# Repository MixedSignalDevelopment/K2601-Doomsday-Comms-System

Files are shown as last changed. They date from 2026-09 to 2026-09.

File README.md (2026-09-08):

# Doomsday Comms System (D.C.S.) — Customer Files

**SKU:** OS2601 · **Board revision:** rev B · © Mixed Signal Development GmbH

This package contains everything needed to review, fabricate, assemble, and
re-flash the Doomsday Comms System board — a two-unit personal LoRa text
messenger built on an nRF52840 (BLE) + SX1262 (LoRa 868 MHz) with a 128×64 mono
LCD, jog-wheel input, LRA haptics, piezo, and USB-C LiPo charging.

## Contents

| Folder | What's inside |
|---|---|
| [`01_KiCad_Project/`](01_KiCad_Project/) | Editable source design — KiCad 7 schematic + PCB layout |
| [`02_Gerbers/`](02_Gerbers/) | Fabrication data — RS-274X gerbers + Excellon drills (4-layer) |
| [`03_BOM/`](03_BOM/) | Bill of materials (rev B) with MPNs and LCSC part numbers |
| [`04_3D_Model/`](04_3D_Model/) | Full assembly 3D model (STEP) for enclosure/mechanical fit |
| [`05_Firmware/`](05_Firmware/) | Source firmware (PlatformIO) — bring-up tester + messenger apps |

Each folder has its own `README.md` with the specifics.

## Ownership & licensing

- Design © 2026 **Mixed Signal Development GmbH**.
- **Firmware** is released under the **MIT License** — see
  [`05_Firmware/LICENSE`](05_Firmware/LICENSE).

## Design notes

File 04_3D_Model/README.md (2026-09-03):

# 3D Model

Enclosure design for the assembled Doomsday Comms System (D.C.S., SKU OS2601) board,
for mechanical fit, enclosure design, and review.

## File

- `K2601 DCS.step` —  Enclosure, **STEP (AP214)** format.

## Usage

Open in any MCAD tool that reads STEP (Fusion 360, SolidWorks, FreeCAD,
Onshape, Solid Edge, etc.). Use it to check connector and control placement
(USB-C, jog wheel, LCD window, antenna u.FL/SMA) against the enclosure.

> This is the authoritative mechanical reference for the whole board. The
> per-component 3D models referenced inside the KiCad PCB are **not** bundled
> (see [`../01_KiCad_Project/`](../01_KiCad_Project/)); this STEP file is what you
> need for mechanical work.

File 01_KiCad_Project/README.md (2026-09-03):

# KiCad Project — Schematic & PCB

Editable source design for the Doomsday Comms System (D.C.S., SKU OS2601),
board rev B.

## Files

| File / folder | Description |
|---|---|
| `dcs.kicad_pro` | KiCad project file — open this one |
| `dcs.kicad_sch` | Schematic |
| `dcs.kicad_pcb` | PCB layout (4-layer) |
| `fp-lib-table` | Footprint-library table (project-relative, points at `Misc.pretty`) |
| `Misc.pretty/` | Bundled custom footprint library (`GSC1031YB`) |
| `3D/` | Bundled component 3D models referenced by the PCB |

## Requirements

- **KiCad 7.0 or newer** (the project was authored in KiCad 7).

Open `dcs.kicad_pro` in KiCad, then open the schematic and PCB editors from
the project window.

## Self-contained — no external libraries needed

This project has **no dependency on any machine-specific library path**. It opens
complete on a fresh KiCad install:

- **Footprints** are embedded directly in `dcs.kicad_pcb` (every placed footprint
  carries its full pad/graphics definition), so the layout opens, edits, and
  fabricates without any library at all.
- **Symbols** are cached in `dcs.kicad_sch`, so the schematic opens standalone
  too.
- The one **custom footprint library** the design uses (`GSC1031YB`) is bundled
  in `Misc.pretty/`, and `fp-lib-table` references it with the project-relative
  `${KIPRJMOD}/Misc.pretty` — so you can also place that part into new layouts.
- The per-part **3D models** are bundled in `3D/`; the PCB references them with
  the project-relative `${KIPRJMOD}/3D/…`, so the 3D viewer resolves them with no
  setup. (For a single complete model of the assembled board, the STEP in
  [`../04_3D_Model/`](../04_3D_Model/) is also provided.)

All original absolute local paths were removed — nothing points outside this
folder. The `.kicad_prl` (per-user GUI state) and editor history were not
included.

## Key components

nRF52840 module (Ebyte E73-2G4M08S1C) · SX1262 LoRa (Ai-Thinker Ra-01SH) ·
ST7565 128×64 LCD (GMG12864-06D) · DRV2605L LRA haptics · MCP73833 LiPo charger ·
TLV75533 LDO · TM-1011A jog wheel.

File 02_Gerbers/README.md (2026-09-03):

# Gerbers & Drill Files

Fabrication data for the Doomsday Comms System (D.C.S., SKU OS2601), board
rev B. Generated from KiCad 7. Internal CAD name: **Messager**.

## Board stackup — 4 copper layers

| File | Layer |
|---|---|
| `Messager-F_Cu.gbr` | Top copper |
| `Messager-In1_Cu.gbr` | Inner copper 1 |
| `Messager-In2_Cu.gbr` | Inner copper 2 |
| `Messager-B_Cu.gbr` | Bottom copper |
| `Messager-F_Mask.gbr` / `Messager-B_Mask.gbr` | Solder mask (top / bottom) |
| `Messager-F_Paste.gbr` / `Messager-B_Paste.gbr` | Solder paste stencil (top / bottom) |
| `Messager-F_Silkscreen.gbr` / `Messager-B_Silkscreen.gbr` | Silkscreen (top / bottom) |
| `Messager-Edge_Cuts.gbr` | Board outline |
| `Messager-PTH.drl` | Plated through-holes (Excellon) |
| `Messager-NPTH.drl` | Non-plated holes (Excellon) |
| `Messager-job.gbrjob` | Gerber job file (manifest tying the set together) |

## Formats

- Gerbers: **RS-274X**.
- Drills: **Excellon**.

## Fabrication

A ready-to-upload archive is provided:

- **`OS2601_DCS_RevB_Gerbers.zip`** — all 14 fabrication files, flat (no
  subfolders), ready to drop into a fab's upload form.

Upload it to your PCB fabricator (JLCPCB, PCBWay, Aisler, etc.) and specify a
**4-layer** board. Confirm finished thickness, copper weight, and surface finish
with the vendor per your requirements. (The loose files are also left in this
folder if you prefer to inspect or re-zip them.)

> The gerber/drill filenames keep the internal design name `Messager-*` — only
> the KiCad project and firmware were renamed to `dcs`/OS2601. This is the same
> board; the names are irrelevant to fabrication. Keep them as-is —
> `Messager-job.gbrjob` references the other files by name, so renaming
> individual gerbers would break the job manifest.

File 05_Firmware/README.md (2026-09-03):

# Doomsday Comms System — D.C.S. (SKU OS2601) — bring-up firmware

Menu-driven peripheral tester for the rev-A board (nRF52840 + SX1262),
programmed and debugged over **SWD with an ST-Link V2** (no USB). This is
**not** Meshtastic yet — it is the "bare test firmware" used to prove out every
net before Meshtastic is layered on top. The pin map is encoded once, as a
proper Arduino board variant, so the same variant folder drops into a
Meshtastic build later.

Because there is no USB serial, the console runs over **SEGGER RTT** on the SWD
link: the firmware keeps a text ring-buffer in RAM and OpenOCD serves it as a
bidirectional terminal on `localhost:9090`.

```
platformio.ini                board/env definition + libraries + ST-Link/RTT
boards/dcs_nrf52840.json      custom PlatformIO board (Adafruit nRF52 core)
variants/dcs/                 variant.h + variant.cpp = the authoritative pin map
src/bringup/main.cpp          the bring-up tester (on-LCD wheel-driven menu)
lib/rtt/                       Arduino Stream wrapper over the core's SEGGER RTT
softdevice/                    where the s140 SoftDevice hex goes (not shipped, see below)
flash_softdevice.cfg          OpenOCD: mass-erase + flash the SoftDevice
openocd_rtt.cfg               OpenOCD script: attach ST-Link + serve RTT console
.vscode/tasks.json           SoftDevice flash + "RTT server" + "RTT console" tasks
```

## What it does

The whole tester runs **on the LCD**, driven by the thumbwheel — no host needed.
At boot it shows a splash, turns the backlight on, and drops into a scrolling
main menu. RTT (over SWD) just mirrors a boot/event log for debugging.

**Navigation** (only three inputs exist — wheel R, wheel L, wheel PUSH):

| input | action |
|---|---|
| roll R / L | move the selection, or adjust a value |
| PUSH short (<700 ms)| select / activate |
| PUSH long (>700 ms) | back to the main menu |

> **rev-A note:** SW3's footprint was mis-wired; after a hardware bodge the
> switch works but on swapped pins — firmware maps **P0.12 = press,
> P0.07 = roll R, P0.13 = roll L** (`pollInputs()` in `main.cpp`). Rev-B should
> correct the SW3 footprint so no swap is needed. The RTT console keyboard also
> navigates (`w`/`s` = up/down, `Enter`/space = select, `b` = back), and the
> "Input diagnostic" menu item shows the raw switch pins.

**Menu items** (each maps to a step in the hardware bring-up order):

| item | what it tests | step |
|---|---|---|
| Display + contrast | patterns (frame / all-on / checker / stripes); roll adjusts contrast live | 3 |
| Backlight | roll adjusts PWM brightness | 3 |
| Wheel test | live R / L / PUSH counters + state | 4 |
| Haptic (LRA) | roll picks DRV2605 ROM effect 1–123; push plays | 5 |
| Buzzer tone | roll sets 2–5 kHz; push beeps (single-ended) | 5 |
| Buzzer sweep | 3.6→4.4 kHz resonance sweep | 5 |
| Buzzer LOUD | 4 kHz complementary (antiphase) drive, +6 dB | 5 |
| Battery | live VBAT_MON in mV + bar + status | 7 |
| Radio status | SX1262 SPI init (EU868, DIO2 switch, no TCXO); push = 1 TX (needs antenna) | 6 |
| Sleep (System OFF) | deep-sleep, wake on wheel press | — |

The board's safety rules are honoured in code: **TXEN (P0.28) is never
configured or driven**, `DIO2_AS_RF_SWITCH` is enabled, TCXO is disabled, and
sleep drops LRA_EN / backlight / LCD / radio before System OFF.

---

## Wiring the ST-Link V2

Connect the ST-Link V2 to the TC2030 / SWD header:

| ST-Link V2 pin | board |
|---|---|
| SWDIO | SWDIO |
| SWCLK | SWDCLK |
| GND | GND |
| 3.3V | 3V3 (or power the board from the bench PSU / USB-C) |
| RST (optional) | P0.18 RESET|

The bench PSU can stand in for the battery as usual; the ST-Link only needs
SWDIO/SWCLK/GND to program and to carry the RTT console.

---

## Why a one-time SoftDevice flash is needed

This uses the Adafruit nRF52 core, whose only linker script places the app at
**0x26000** for the **s140 SoftDevice** memory layout. The app therefore cannot
boot unless the SoftDevice (with its MBR at 0x0) is present — a raw app-only
flash programs fine and verifies, but the CPU never reaches `setup()`.

We deliberately **skip the Adafruit UF2/DFU bootloader** (it refuses to
chain-load a raw-flashed app and just sits in DFU). Instead we flash
**MBR + SoftDevice only** (`softdevice/s140_6.1.1_mbr.hex`); with no UICR
bootloader pointer set, the MBR boots SoftDevice → app directly. This is a
one-time step (the equivalent of "flash the bootloader once"); the SoftDevice
survives every subsequent app upload.

> **The SoftDevice hex is not included in this repository.** Nordic's s140 is
> proprietary and is not redistributable here, so you must supply
> `softdevice/s140_6.1.1_mbr.hex` yourself before the flash step below — see
> [`softdevice/README.md`](softdevice/README.md) for where to obtain it.

> The chip does **not** need a pyOCD APPROTECT recovery — this board's nRF52840
> was not locked. If you ever hit a genuinely locked part, `python -m pyocd
> erase --mass -t nrf52840` clears it, but you won't normally need it.

---

## Run it from VS Code

### One-time setup
1. Open this `Firmware` folder in VS Code (**File → Open Folder**).
2. When prompted, install the recommended **PlatformIO IDE** extension
   (`platformio.platformio-ide`). It bundles its own toolchain (and OpenOCD) —
   you do **not** need Python or `pio` on your PATH. First launch downloads the
   nRF52 toolchain (a few minutes).
3. Reopen the folder once PlatformIO finishes initialising. A small **PlatformIO
   toolbar** (house / ✓ / → icons) appears in the blue status bar at the bottom.

### Build
- Click the **✓ (Build)** button in the status bar (or `Ctrl+Alt+B`).
- First build pulls U8g2, Adafruit DRV2605 and RadioLib automatically.
- Verified building clean here: RAM ~5%, Flash ~13%.

### Flash the SoftDevice — ONE TIME, before the first upload
- **Terminal → Run Task… → "Flash SoftDevice (one-time, before first upload)"**.
  This mass-erases and writes MBR + s140. Do it once per board (or after any
  mass-erase). Then continue to Upload below.

### Flash the app over SWD (ST-Link)
- Click the **→ (Upload)** button (or `Ctrl+Alt+U`). PlatformIO drives OpenOCD
  with the ST-Link (plain `swd` transport) to program the app at 0x26000. The
  SoftDevice underneath boots it. Re-run this for every code change.

### Open the RTT console (this is your bring-up terminal)
The console is not a COM port — it comes over SWD via RTT, in two steps:

1. **Terminal → Run Task… → "RTT: OpenOCD server (start first)"**
   — attaches the ST-Link and serves the console on `localhost:9090`.
   Leave this running.
2. **Terminal → Run Task… → "RTT console"**
   — opens the interactive terminal (PlatformIO monitor on `socket://localhost:9090`).

Now press `h` for the menu, then the single-letter commands in the table above.
Typing goes to the board; test output comes back. That terminal *is* your
bring-up console.

> One ST-Link can only be owned by one tool at a time. Upload first (releases
> the probe), then start the OpenOCD server task. If a task can't connect,
> make sure no debug session or other OpenOCD is still holding the probe.

### Source-level debugging (breakpoints)
ST-Link + nRF52 debugging is wired up: **Run → Start Debugging (F5)** launches
OpenOCD + GDB and halts at `setup()`. Set breakpoints, inspect variables, step.
Note this F5 session owns the ST-Link, so stop it before using the RTT tasks
(and vice-versa). For day-to-day bring-up the RTT console is the faster loop.

---

## Command-line equivalent (if you prefer)
PlatformIO installs a CLI at `~/.platformio/penv/Scripts/pio.exe`:
```
pio run                 # build
pio run -t upload       # flash over SWD via ST-Link
# then, for the console:
~/.platformio/packages/tool-openocd/bin/openocd -f openocd_rtt.cfg      # server
pio device monitor --port socket://localhost:9090 --echo               # terminal
```

## Troubleshooting

- **Flash "Verified OK" but nothing runs (no RTT, `setup()` never hit)** — the
  SoftDevice isn't present. Run the one-time **Flash SoftDevice** task, then
  Upload the app again. (Symptom when halted: PC sits below 0x26000.)
- **OpenOCD: "Debug adapter doesn't support 'hla_swd' transport"** — the platform
  default; this project already overrides it to plain `swd` in `platformio.ini`
  and the `.cfg` files. If you add your own OpenOCD invocation, use
  `-c "transport select swd"`, not `hla_swd`.
- **pyOCD `STLink error (29): Bad AP`** — pyOCD's AP scan tripping on this
  ST-Link when it probes the (absent) next access port; it does *not* mean the
  chip is locked. We use OpenOCD (not pyOCD) for flashing, which is unaffected.
- **RTT console is blank** — make sure the OpenOCD server task is running and
  the firmware is actually running (an F5 debug session halts at `setup()` — hit
  Continue). The console only prints once code runs.
- **"unknown command: rtt"** in the OpenOCD task — your bundled OpenOCD is old;
  update PlatformIO (`pio upgrade` / update the PlatformIO IDE extension), which
  pulls a newer `tool-openocd`.
- **Display garbled / shifted a few pixels** — GMG12864 panels vary; in
  `src/main.cpp` swap the `U8G2_ST7565_ERC12864_F_4W_SW_SPI` constructor for the
  `..._ALT_...` variant, or an `NHD_C12864` / `LM6059` profile, and re-tune
  `setContrast()`.
- **Probe busy** — only one of {Upload, F5 debug, RTT OpenOCD task} can own the
  ST-Link at a time. Stop the others first.

## Next step after bring-up
Once every net checks out, this `variants/dcs/` folder is copied into a
Meshtastic firmware checkout as a custom board variant, and the UI becomes a
custom Meshtastic module.

## License
Firmware in this repository is released under the **MIT License** (see
[`LICENSE`](LICENSE)) — © 2026 **Mixed Signal Development GmbH**. When the
hardware design files (schematics, PCB) are published, the customary pairing is
a hardware licence such as **CERN-OHL-S**; this repo covers the firmware only.

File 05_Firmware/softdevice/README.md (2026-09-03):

# SoftDevice (not included)

The Nordic **s140 v6.1.1** SoftDevice is proprietary and is **not redistributed**
in this repository (see Nordic's Software Development Kit license). You must
supply it yourself before the one-time flash step.

## What you need

A combined **MBR + s140 6.1.1** Intel-HEX image named:

```
softdevice/s140_6.1.1_mbr.hex
```

`flash_softdevice.cfg` expects exactly this path/name.

## Where to get it

The matching SoftDevice ships with the Adafruit nRF52 Arduino core (the same
core this project builds against). After PlatformIO has fetched the framework,
it is under:

```
~/.platformio/packages/framework-arduinoadafruitnrf52/cores/nRF5/nordic/softdevice/s140_nrf52_6.1.1_API/
```

and the raw hex is distributed with the Nordic **nRF5 SDK** / the S140 6.1.1
release on Nordic Semiconductor's website. Combine the MBR + SoftDevice into a
single hex (or use the pre-combined image from the Adafruit bootloader release
assets) and save it to the path above.

Because it is proprietary, the file is listed in `.gitignore` — keep it out of
any public fork.

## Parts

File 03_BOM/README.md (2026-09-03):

# Bill of Materials

Production BOM for the Doomsday Comms System (D.C.S., SKU OS2601), board rev B.

## File

- `OS2601_DCS_RevB_BOM.xlsx` — 27 line items, 44 components.

## Columns

- **Placed** — a checkbox column for hand-assembly / line tracking.
- **Designators** — reference designators (e.g. `C1–C4`, `U2`).
- **Value** — component value.
- **Package** — footprint / package (0805, 0603, SOT-23, MSOP-10, …).
- **Qty** — quantity per board.
- **MPN** — manufacturer part number.
- **Notes** — includes **LCSC part numbers** (e.g. `C354262`) for direct ordering,
  plus alternates where called out.

The list is grouped for assembly convenience (SMD passives first, then ICs and
transistor, etc.).

## Sourcing note

LCSC part numbers are given for most parts for convenient ordering / JLCPCB
assembly. A few parts (e.g. the 10 µF `CL21B106KOQNNNE`) have no LCSC number and
should be ordered by **MPN**. Always verify availability and package/value before
placing an order.

> This is the **production** BOM. An internal costing BOM exists but is
> intentionally **not** included in this package.

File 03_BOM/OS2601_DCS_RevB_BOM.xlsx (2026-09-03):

OS-K2601 Messager — Bill of Materials
Rev B · nRF52 BLE + LoRa · USB-C LiPo charging · 27 line items · 44 components
Placed | Designators | Value | Package | Qty | MPN | LCSC OC | Notes
1 · SMD passives (0805 / 0603) flattest parts first
☐ | C1–C4 | 4.7µF | 0805 | 4 | CL21A475KAQNNNE | C354262
☐ | C6, C11 | 1µF | 0805 | 2 | CC0805KKX7R7BB105 | C91186
☐ | C9, C10, C13, C14, C16 | 100nF | 0805 | 5 | CC0805KRX7R9BB104 | C396718
☐ | C12, C15 | 10µF | 0805 | 2 | CL21B106KOQNNNE | C95841 | No LCSC # — order by MPN
☐ | R1, R2 | 5.1k | 0805 | 2 | RC0805FR-075K1L | C84375
☐ | R3 | 2k | 0805 | 1 | RC0805JR-072KL | C114748
☐ | R4 | 22R | 0805 | 1 | RC0805FR-0722RL | C107702
☐ | R5 | 100k | 0805 | 1 | RC0805FR-07100KL | C96346
☐ | R6–R8, R11, R12, R15 | 4.7k | 0805 | 6 | RC0805FR-074K7L | C60816
☐ | R9, R10 | 1M | 0805 | 2 | RC0805FR-071ML | C706228
☐ | R13, R14 | 100R | 0805 | 2 | RC0805FR-07100RL | C105577 | Alt LCSC: C2907218
☐ | F1 | 1A fuse | 0603 | 1 | JB06F1001R | C151139 | No LCSC # — order by MPN
☐ | TH1 | 10k NTC | 0603 | 1 | NTCG164BH103HT1 | C415353
2 · SMD ICs & transistor use flux — mind pin 1
☐ | Q1 | 2N7002 | SOT-23 | 1 |  | C916396
☐ | U2 | MCP73833 | MSOP-10 | 1 | MCP73833T-AMI/UN |  | Mind pin 1 · no LCSC #, cheaper on Digikey
☐ | U3 | TLV75533 | SOT-23-5 | 1 | TLV75533PDYDR | C28642215
☐ | U7 | DRV2605L | MSOP-10 | 1 | DRV2605LDGSR | C527464 | Mind pin 1
3 · LED & switches LED is directional
☐ | D1 | Side LED | 4×1.4mm | 1 | XL-4008SURC | C2843771 | Polarity — check cathode mark
☐ | SW1 | Push button | Side SMD | 1 | MPTCLG-Q-T/R | C240296
☐ | SW3 | Slide switch | TM-1011A | 1 | TM-1011A | C318960
4 · Modules & sounder keep antennas clear of solder
☐ | U1 | E73-2G4M08S1C | SMD module | 1 | E73-2G4M08S1C | C356849 | nRF52 BLE
☐ | U8 | Ra-01SH | SMD module | 1 | Ra-01SH | C2764087 | LoRa
☐ | U4 | GSC1031YB-3V4000 | SMD buzzer | 1 | GSC1031YB-3V4000 | C255331
☐ |  | Antenna |  | 1 | ANT-868-CW-HD-SMA | Link (https://www.digikey.ch/en/products/detail/te-connectivity-linx/ANT-868-CW-HD-SMA/5592339)
☐ |  | VG0832012 | LRA | 1 | VG0832012 | Link (https://www.digikey.ch/en/products/detail/vybronics-inc/VG0832012/7364317)
☐ | M1 | 12864 display | Module | 1 | 12864-06D | Link (https://de.aliexpress.com/item/1005010600373201.html)
5 · Connectors & programming last — the tall parts
☐ | J1 | PH2.0 battery | JST SMD | 1 |  | C295747 | Check battery polarity
☐ | J2 | USB-C 16P | USB-C SMD | 1 | TYPE-C 16PIN 2MD(073) | C2765186
☐ | TC1 | TC2030-IDC | Tag-Connect | 1 |  |  | Pads only — no part fitted
☐ → pick ☑ from the dropdown (or tick on paper) as you place each part. Solder top to bottom, flattest first. Mixed Signal Development · mixedsignaldev.com

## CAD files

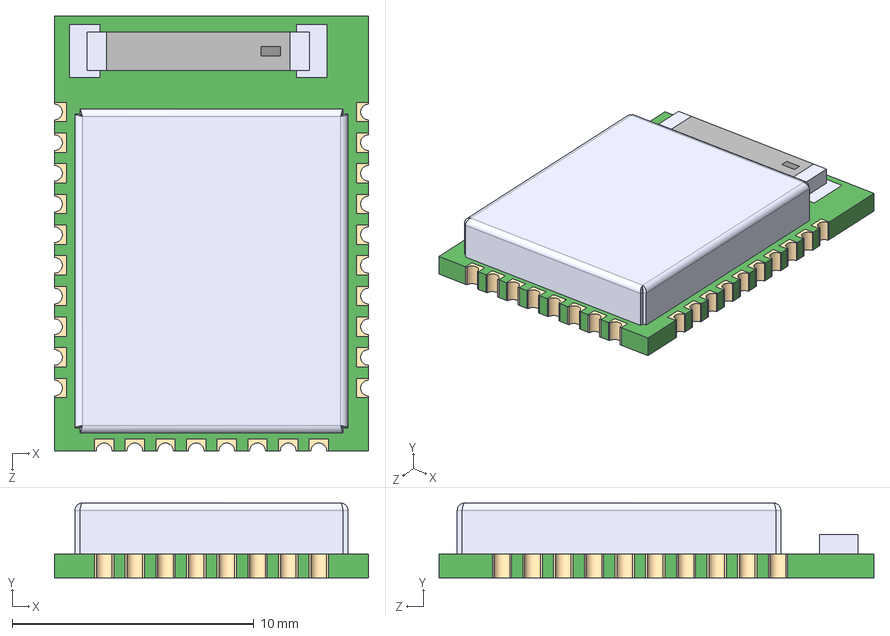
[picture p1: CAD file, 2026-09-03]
01_KiCad_Project/3D/E73-2G4M08S1C.step
13.0 x 3.10 x 18.0 mm

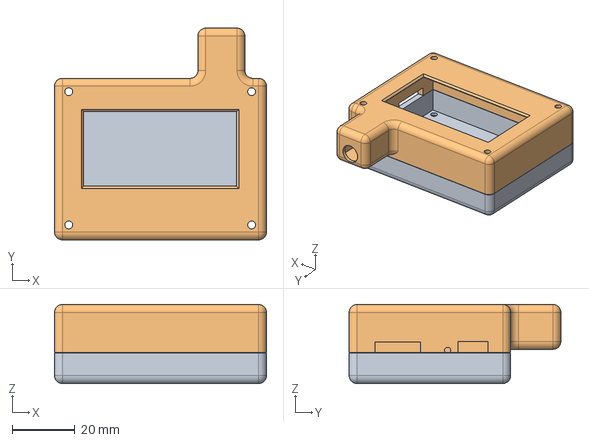
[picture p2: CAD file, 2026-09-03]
04_3D_Model/K2601 DCS.step
67.6 x 67.5 x 25.2 mm

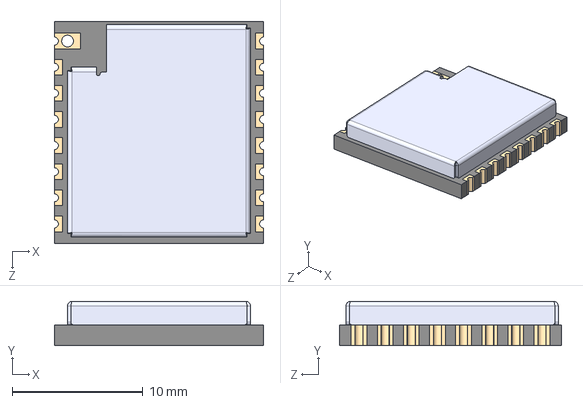
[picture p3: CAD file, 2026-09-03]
01_KiCad_Project/3D/RA-01H.STEP
16.0 x 3.40 x 17.0 mm

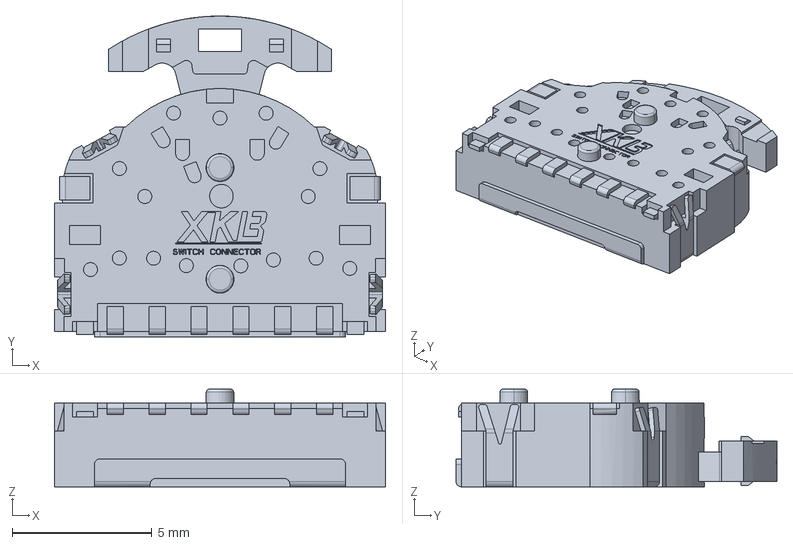
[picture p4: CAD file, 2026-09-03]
01_KiCad_Project/3D/TM-1011A.stp
11.9 x 11.5 x 3.50 mm

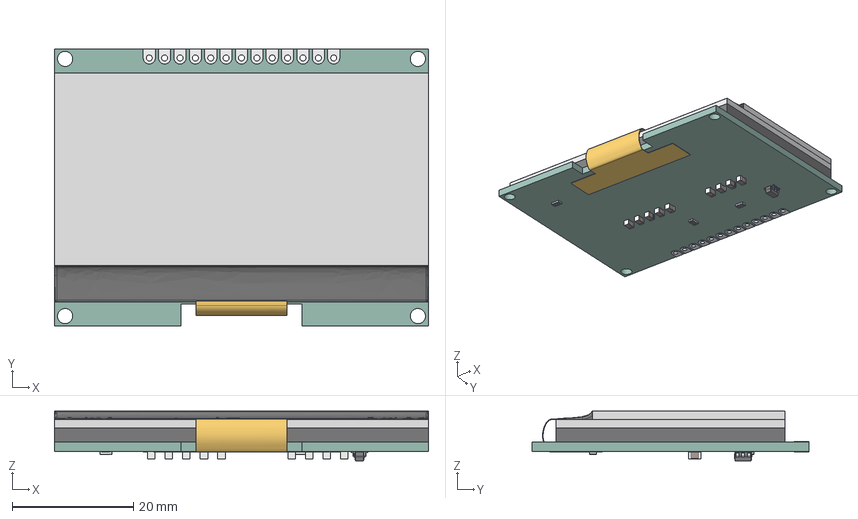
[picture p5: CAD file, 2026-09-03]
01_KiCad_Project/3D/GMG12864-06D.step
61.8 x 45.8 x 8.25 mm
PCB
LED-box
Back glass
Front glass
Ribbon cable
Resin
Hole plates
C_0805_2012Metric x 9
SOT-23-6
R_0805_2012Metric x 3

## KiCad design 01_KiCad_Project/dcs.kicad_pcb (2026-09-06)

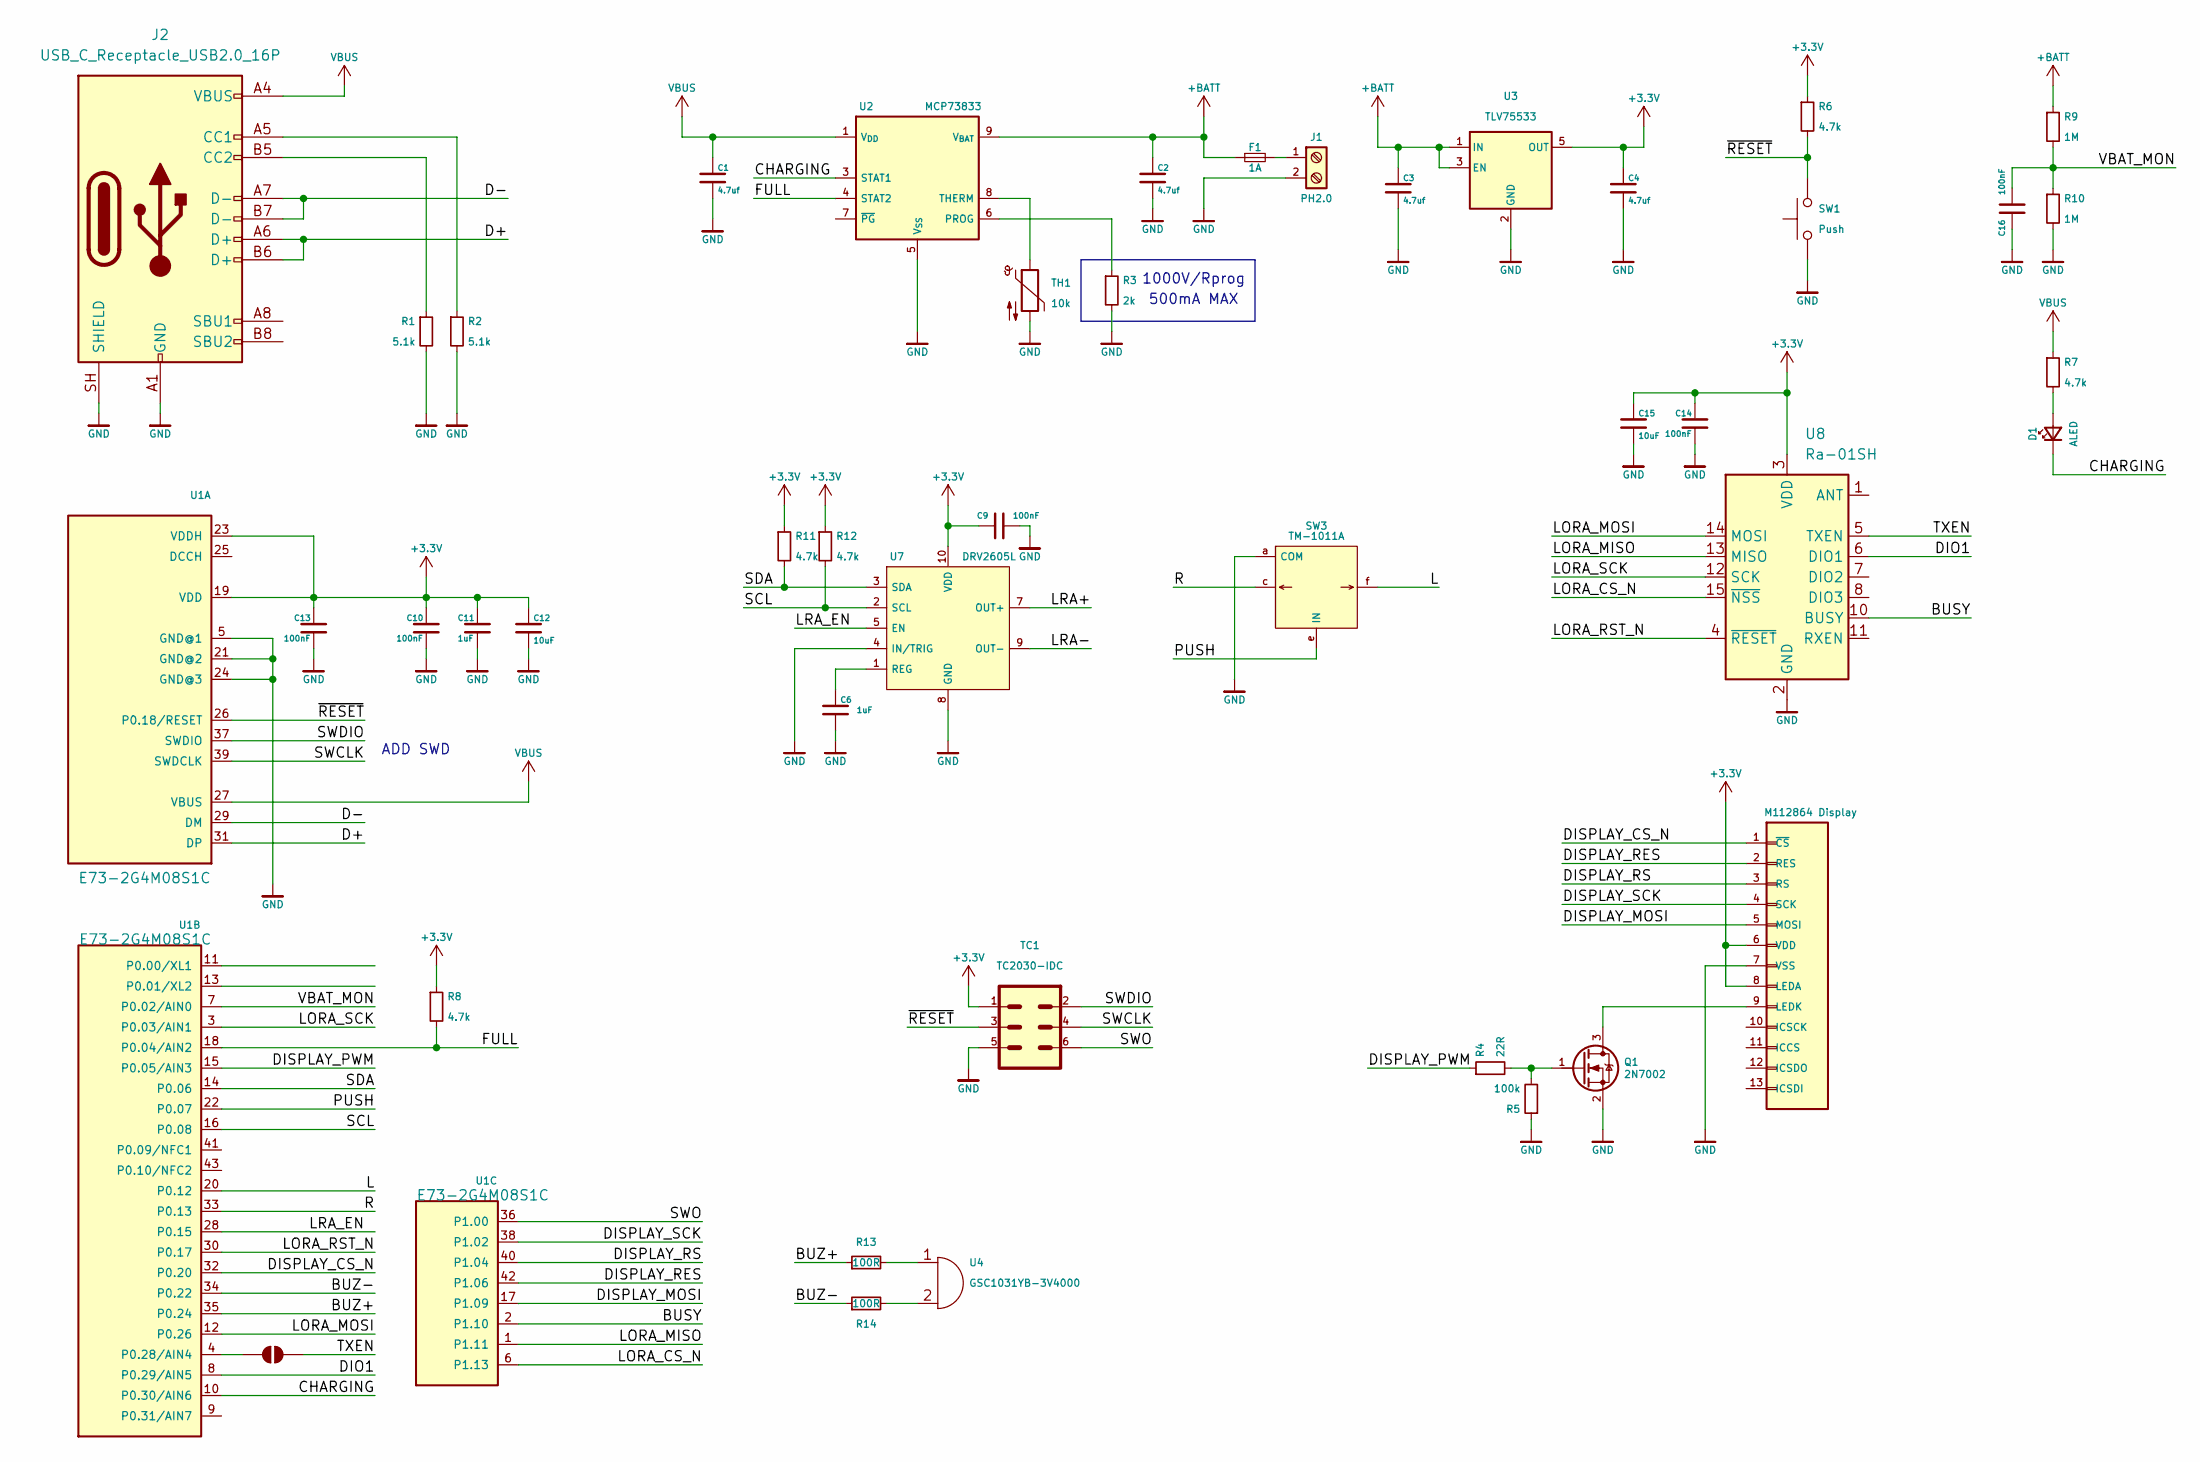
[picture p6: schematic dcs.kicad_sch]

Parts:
C1, C2, C3, C4: 4.7uf; C_0805; MPN CL21A475KAQNNNE; LCSC OC C354262
C6, C11: 1uF; C_0805; MPN CC0805KKX7R7BB105; LCSC OC C91186
C9, C10, C13, C14, C16: 100nF; C_0805; MPN CC0805KRX7R9BB104; LCSC OC C396718
C12, C15: 10uF; C_0805; MPN CL21B106KOQNNNE
D1: ALED; SideLED_4x1.4mm; MPN XL-4008SURC; LCSC OC C2843771
F1: 1A; R_0603; MPN JB06F1001R
J1: PH2.0; JST_PH_S2B-PH-SM4-TB_1x02-1MP_P2.00mm_Horizontal; LCSC OC C295747
J2: USB_C_Receptacle_USB2.0_16P; USB_C_16P_Horizontal; MPN TYPE-C 16PIN 2MD(073); LCSC OC C2765186
JP1: SolderJumper_2; SolderJumper-2_P1.3mm_Open_RoundedPad1.0x1.5mm
M1: 12864 Display; 12864DisplayModule
Q1: 2N7002; SOT-23; LCSC OC C916396
R1, R2: 5.1k; R_0805; MPN RC0805FR-075K1L; LCSC OC C84375
R3: 2k; R_0805; MPN RC0805JR-072KL; LCSC OC C114748
R4: 22R; R_0805; MPN RC0805FR-0722RL; LCSC OC C107702
R5: 100k; R_0805; MPN RC0805FR-07100KL; LCSC OC C96346
R6, R7, R8, R11, R12: 4.7k; R_0805; MPN RC0402FR-074K7L; LCSC OC C60816
R9, R10: 1M; R_0805; MPN RC0805FR-071ML; LCSC OC C706228
R13, R14: 100R; R_0805; MPN RC0805FR-07100RL; LCSC OC C105577
SW1: Push; SideSwitch; MPN MPTCLG-Q-T/R; LCSC OC C240296
SW3: TM-1011A; SlideKnob; MPN TM-1011A; LCSC OC C318960
TC1: TC2030-IDC
TH1: 10k; R_0603; MPN NTCG164BH103HT1; LCSC OC C415353
U1: E73-2G4M08S1C; MPN E73-2G4M08S1C; LCSC OC C356849
U2: MCP73833; MSOP-10_3x3mm_P0.5mm; MPN MCP73833T-AMI/UN
U3: TLV75533; SOT-23-5; MPN TLV75533PDYDR; LCSC OC C28642215
U4: GSC1031YB-3V4000; GSC1031YB; MPN GSC1031YB-3V4000; LCSC OC C255331
U7: DRV2605L; MSOP-10_3x3mm_P0.5mm; MPN DRV2605LDGSR; LCSC OC C527464
U8: Ra-01SH; Ai-Thinker-Ra-01-LoRa; MPN Ra-01SH; LCSC OC C2764087

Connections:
+3.3V: C4.1, C9.1, C10.1, C11.1, C12.1, C13.1, C14.1, C15.1, M1.6 (VDD), M1.8 (LEDA), R6.1, R8.1, R11.1, R12.1, TC1.1, U1.19 (VDD), U1.23 (VDDH), U3.5 (OUT), U7.6 (VDD/NC), U7.10 (VDD), U8.3 (VDD)
+BATT: C2.1, C3.1, F1.1, R9.1, U2.9 (V_{BAT}), U2.10 (V_{BAT}), U3.1 (IN), U3.3 (EN)
/BUSY: U1.2 (P1.10), U8.10 (BUSY)
/BUZ+: R13.1, U1.35 (P0.24)
/BUZ-: R14.1, U1.34 (P0.22)
/CHARGING: D1.C, U1.10 (P0.30/AIN6), U2.3 (STAT1)
/D+: J2.A6 (D+), J2.B6 (D+), U1.31 (DP)
/D-: J2.A7 (D-), J2.B7 (D-), U1.29 (DM)
/DIO1: U1.8 (P0.29/AIN5), U8.6 (DIO1)
/DISPLAY_CS_N: M1.1 (~CS), U1.32 (P0.20)
/DISPLAY_MOSI: M1.5 (MOSI), U1.17 (P1.09)
/DISPLAY_PWM: R4.1, U1.15 (P0.05/AIN3)
/DISPLAY_RES: M1.2 (RES), U1.42 (P1.06)
/DISPLAY_RS: M1.3 (RS), U1.40 (P1.04)
/DISPLAY_SCK: M1.4 (SCK), U1.38 (P1.02)
/FULL: R8.2, U1.18 (P0.04/AIN2), U2.4 (STAT2)
/L: SW3.f, SW3.g, U1.20 (P0.12)
/LORA_CS_N: U1.6 (P1.13), U8.15 (~NSS)
/LORA_MISO: U1.1 (P1.11), U8.13 (MISO)
/LORA_MOSI: U1.12 (P0.26), U8.14 (MOSI)
/LORA_RST_N: U1.30 (P0.17), U8.4 (~RESET)
/LORA_SCK: U1.3 (P0.03/AIN1), U8.12 (SCK)
/LRA+: U7.7 (OUT+)
/LRA-: U7.9 (OUT-)
/LRA_EN: U1.28 (P0.15), U7.5 (EN)
/PUSH: SW3.e (IN), U1.22 (P0.07)
/R: SW3.c, SW3.d, U1.33 (P0.13)
/SCL: R12.2, U1.16 (P0.08), U7.2 (SCL)
/SDA: R11.2, U1.14 (P0.06), U7.3 (SDA)
/SWCLK: TC1.4, U1.39 (SWDCLK)
/SWDIO: TC1.2, U1.37 (SWDIO)
/SWO: TC1.6, U1.36 (P1.00)
/TXEN: JP1.2 (B), U8.5 (TXEN)
/VBAT_MON: C16.2, R9.2, R10.1, U1.7 (P0.02/AIN0)
/~RESET: R6.2, SW1.2, TC1.3, U1.26 (P0.18/RESET)
GND: C1.2, C2.2, C3.2, C4.2, C6.2, C9.2, C10.2, C11.2, C12.2, C13.2, C14.2, C15.2, C16.1, J1.2, J2.A1 (GND), J2.A12 (GND), J2.B1 (GND), J2.B12 (GND), J2.SH (SHIELD), M1.7 (VSS), Q1.2 (S), R1.2, R2.2, R3.2, R5.1, R10.2, SW1.1, SW3.a (COM), SW3.b (COM), TC1.5, TH1.2, U1.5 (GND@1), U1.21 (GND@2), U1.24 (GND@3), U2.5 (V_{SS}), U3.2 (GND), U7.4 (IN/TRIG), U7.8 (GND), U8.2 (GND), U8.9 (GND), U8.16 (GND)
unnamed: D1.A, R7.2
unnamed: F1.2, J1.1
unnamed: J2.A5 (CC1), R2.1
unnamed: J2.B5 (CC2), R1.1
unnamed: JP1.1 (A), U1.4 (P0.28/AIN4)
unnamed: M1.9 (LEDK), Q1.3 (D)
unnamed: Q1.1 (G), R4.2, R5.2
unnamed: R13.2, U4.1
unnamed: R14.2, U4.2
unnamed: R3.1, U2.6 (PROG)
unnamed: TH1.1, U2.8 (THERM)
unnamed: C6.1, U7.1 (REG)
VBUS: C1.1, J2.A4 (VBUS), J2.A9 (VBUS), J2.B4 (VBUS), J2.B9 (VBUS), R7.1, U1.27 (VBUS), U2.1 (V_{DD}), U2.2 (V_{DD})

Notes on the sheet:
1000V/Rprog
ADD SWD
500mA MAX

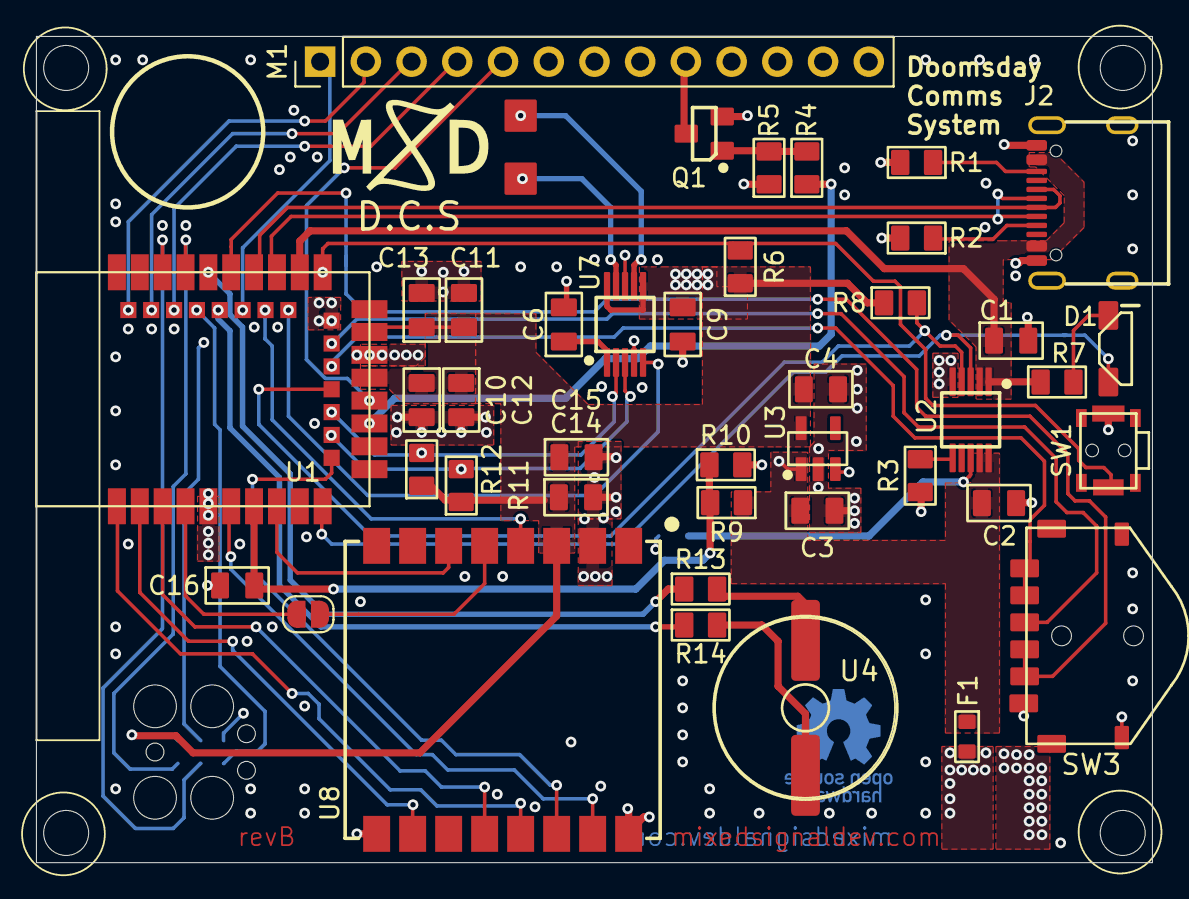
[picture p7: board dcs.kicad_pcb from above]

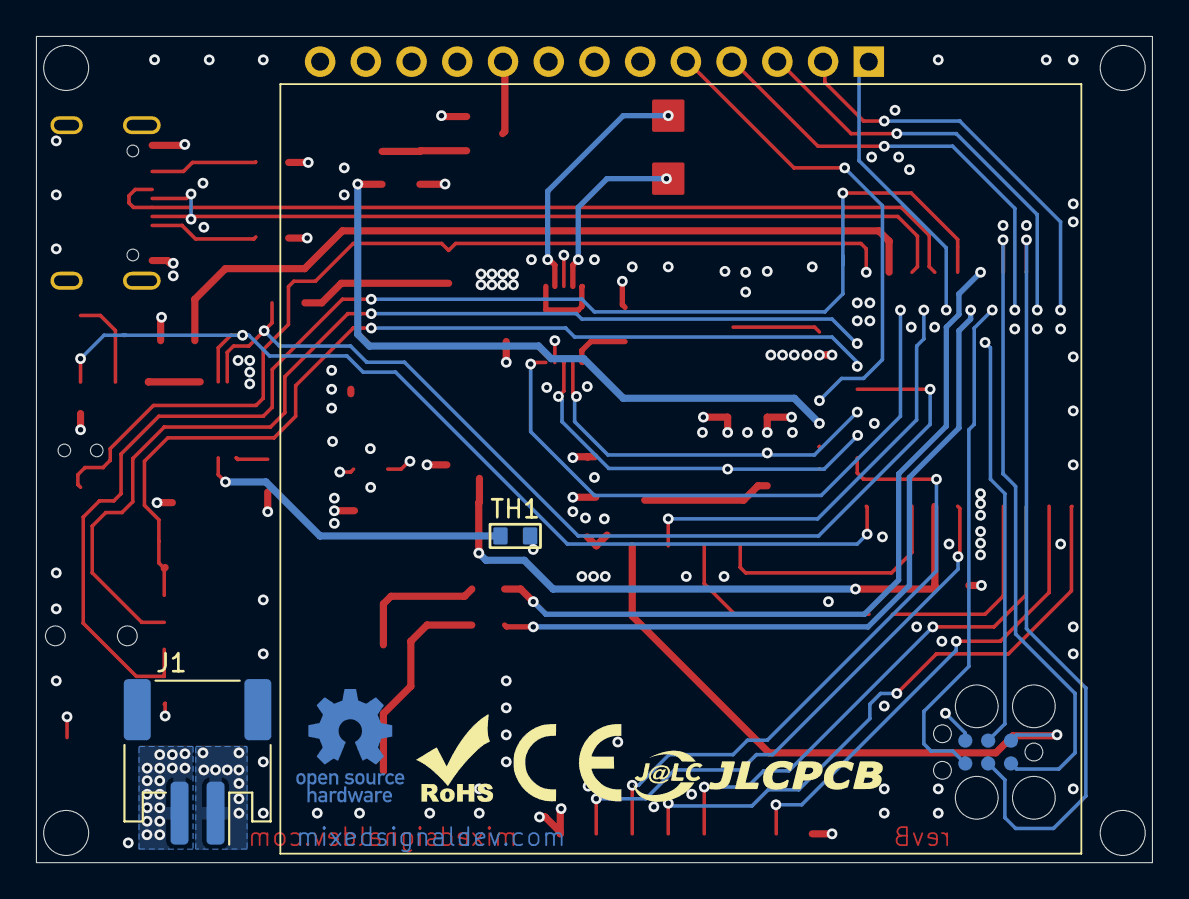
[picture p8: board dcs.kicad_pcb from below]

Board: 4 copper layers, 62.0 x 45.9 mm, 44 parts (3 on the bottom side), 47 nets.

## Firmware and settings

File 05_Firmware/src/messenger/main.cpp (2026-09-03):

/* ===========================================================================
 *  SPDX-License-Identifier: MIT
 *  Copyright (c) 2026 Mixed Signal Development GmbH
 *
 *  Doomsday Comms System (D.C.S., SKU OS2601) — "love notes" point-to-point
 *  messenger
 *
 *  Two identical units. Scroll the wheel to pick a preset message, press to
 *  send it over LoRa to the other unit. Sending previews the animation; when a
 *  message ARRIVES it plays the same animation with a haptic buzz + chime.
 *
 *  Controls (rev-A wheel, post-bodge mapping):
 *     roll  = scroll / adjust      press = send / select      hold = settings
 * =========================================================================== */
#include <Arduino.h>
#include <Wire.h>
#include <SPI.h>
#include <U8g2lib.h>
#include <Adafruit_DRV2605.h>
#include <RadioLib.h>
#include "nrf_gpio.h"
#include "rtt.h"

/* ---- Display (ST7565 128x64 SW-SPI) -------------------------------------- */
#define DISP_ARGS U8G2_R0, PIN_DISPLAY_SCK, PIN_DISPLAY_MOSI, \
                  PIN_DISPLAY_CS_N, PIN_DISPLAY_RS, PIN_DISPLAY_RES
U8G2_ST7565_ERC12864_F_4W_SW_SPI display(DISP_ARGS);

Adafruit_DRV2605 drv;
static bool g_drvReady = false;

SX1262 radio = new Module(PIN_LORA_CS_N, PIN_DIO1, PIN_LORA_RST_N, PIN_BUSY);
static bool  g_radioReady = false;
static float g_lastRssi   = 0;

/* ---- User settings (kept in RAM; persistence is a future add) ------------ */
static uint8_t  g_backlight = 210;   /* PWM 0..255                          */
static uint8_t  g_contrast  = 24;    /* ST7565 electronic volume 0..63      */
static uint8_t  g_hapticLvl = 2;     /* 0 Off, 1 Soft, 2 Med, 3 Strong      */
static uint8_t  g_beepLvl   = 1;     /* 0 Off, 1 On, 2 Loud                 */
static uint8_t  g_sleepIdx  = 2;     /* screen-off timeout index            */

static const uint16_t    kSleepSecs[] = { 0, 15, 30, 60, 120 };
static const char *const kSleepLbl[]  = { "Off", "15s", "30s", "1m", "2m" };
static const char *const kHapLbl[]    = { "Off", "Soft", "Med", "Strong" };
static const char *const kBeepLbl[]   = { "Off", "On", "Loud" };

static uint32_t g_lastActive = 0;
static bool     g_asleep     = false;
static int      g_battMv     = 0;

/* ===========================================================================
 *  Preset messages + which animation plays for each
 * =========================================================================== */
enum Anim { AN_BEAT, AN_FLOAT, AN_BANNER, AN_STARS };
struct Preset { const char *text; uint8_t anim; };
static const Preset kPresets[] = {
    { "I love you",       AN_BEAT   },
    { "I miss you",       AN_FLOAT  },
    { "Thinking of you",  AN_FLOAT  },
    { "You're cute",      AN_BANNER },
    { "Kiss you!",        AN_BEAT   },
    { "Good morning!",    AN_BANNER },
    { "Good night",       AN_STARS  },
    { "Sweet dreams",     AN_STARS  },
    { "Call me?",         AN_BANNER },
    { "Home soon <3",     AN_FLOAT  },
};
static const int kNumPresets = sizeof(kPresets) / sizeof(kPresets[0]);
#define MSG_MAGIC 0xC5                /* packet: [magic][anim][text...] */

/* Long preamble so a duty-cycled receiver can't miss a packet. ~250 symbols at
 * SF9/BW125 = ~1 s: sets both the wake-up latency and the TX airtime overhead.
 * Bigger = longer battery when idle but slower/longer sends; smaller = snappier
 * but the radio must wake more often (more idle current). */
#define PREAMBLE_SYM 250

/* ===========================================================================
 *  Input — three clean contacts after the rev-A bodge:
 *    P0.12 = PRESS, P0.07 = roll R, P0.13 = roll L
 * =========================================================================== */
#define PIN_PRESS   PIN_WHEEL_R
#define PIN_ROLL_R  PIN_PUSH
#define PIN_ROLL_L  PIN_WHEEL_L

enum WheelEv { WH_NONE, WH_DOWN, WH_UP };
enum BtnEv   { BTN_NONE, BTN_SHORT, BTN_LONG };

static void pollInputs(WheelEv &w, BtnEv &b)
{
    w = WH_NONE; b = BTN_NONE;
    const uint32_t DEB = 12, LONG_MS = 600;
    uint32_t now = millis();
    static int lastR = HIGH, lastL = HIGH; static uint32_t tR = 0, tL = 0;
    int r = digitalRead(PIN_ROLL_R), l = digitalRead(PIN_ROLL_L);
    if (r != lastR && now - tR > DEB) { tR = now; lastR = r; if (r == LOW) w = WH_DOWN; }
    if (l != lastL && now - tL > DEB) { tL = now; lastL = l; if (l == LOW) w = WH_UP;   }
    static int lastP = HIGH; static uint32_t tP = 0, downAt = 0; static bool longFired = false;
    int p = digitalRead(PIN_PRESS);
    if (p != lastP && now - tP > DEB) {
        tP = now; lastP = p;
        if (p == LOW) { downAt = now; longFired = false; }
        else if (!longFired) b = BTN_SHORT;
    }
    if (p == LOW && !longFired && now - downAt >= LONG_MS) { longFired = true; b = BTN_LONG; }
}

/* ===========================================================================
 *  Feedback — haptics + piezo, both respect the settings
 * =========================================================================== */
static void backlight(uint8_t d) { analogWrite(PIN_DISPLAY_PWM, d); }

static void drvConfig()               /* (re)apply DRV2605 mode after power-up */
{
    if (!g_drvReady) return;
    drv.useLRA(); drv.selectLibrary(6); drv.setMode(DRV2605_MODE_INTTRIG);
}
static void haptic(uint8_t fx)
{
    if (!g_drvReady || g_hapticLvl == 0) return;
    drv.setWaveform(0, fx); drv.setWaveform(1, 0); drv.go();
}
static void buzz()                    /* feedback buzz scaled by haptic level */
{
    static const uint8_t fx[] = { 0, 1, 16, 47 };
    haptic(fx[g_hapticLvl]);
}

static void beepLoud(uint16_t freq, uint16_t ms)   /* complementary antiphase */
{
    const uint32_t base = 16000000UL;
    uint16_t top = (uint16_t)(base / freq);
    static uint16_t seq[2];
    seq[0] = top / 2; seq[1] = (top / 2) | 0x8000;
    NRF_PWM_Type *pwm = NRF_PWM2;                   /* PWM2: avoid backlight PWM */
    pwm->PSEL.OUT[0] = g_ADigitalPinMap[PIN_BUZ_PLUS];
    pwm->PSEL.OUT[1] = g_ADigitalPinMap[PIN_BUZ_MINUS];
    pwm->ENABLE = 1; pwm->MODE = 0; pwm->PRESCALER = 0; pwm->COUNTERTOP = top; pwm->LOOP = 0;
    pwm->DECODER = (PWM_DECODER_LOAD_Individual << PWM_DECODER_LOAD_Pos) |
                   (PWM_DECODER_MODE_RefreshCount << PWM_DECODER_MODE_Pos);
    pwm->SEQ[0].PTR = (uint32_t)seq; pwm->SEQ[0].CNT = 2;
    pwm->SEQ[0].REFRESH = 0; pwm->SEQ[0].ENDDELAY = 0;
    pwm->TASKS_SEQSTART[0] = 1;
    delay(ms);
    pwm->TASKS_STOP = 1; pwm->ENABLE = 0;
    pinMode(PIN_BUZ_PLUS, OUTPUT);  digitalWrite(PIN_BUZ_PLUS, LOW);
    pinMode(PIN_BUZ_MINUS, OUTPUT); digitalWrite(PIN_BUZ_MINUS, LOW);
}
static void beep(uint16_t f, uint16_t ms)
{
    if (g_beepLvl == 0) return;
    if (g_beepLvl == 2) { beepLoud(f, ms); return; }
    pinMode(PIN_BUZ_MINUS, OUTPUT); digitalWrite(PIN_BUZ_MINUS, LOW);
    tone(PIN_BUZ_PLUS, f); delay(ms);
    noTone(PIN_BUZ_PLUS); digitalWrite(PIN_BUZ_PLUS, LOW);
}

static void chimeIncoming() { buzz(); beep(1568, 90); beep(2093, 90); beep(2637, 150); buzz(); }
static void chimeSent()     { buzz(); beep(2093, 60); beep(2637, 90); }

/* ===========================================================================
 *  Graphics helpers + animations
 * =========================================================================== */
static void textCentered(const char *s, int y, const uint8_t *font)
{
    display.setFont(font);
    display.drawStr((128 - display.getStrWidth(s)) / 2, y, s);
}
static void drawHeart(int cx, int cy, int r)
{
    display.drawDisc(cx - r, cy - r, r); display.drawDisc(cx + r, cy - r, r);
    display.drawTriangle(cx - 2 * r, cy - r, cx + 2 * r, cy - r, cx, cy + 2 * r);
}
static void drawHeartOutline(int cx, int cy, int r)
{
    display.drawCircle(cx - r, cy - r, r); display.drawCircle(cx + r, cy - r, r);
    display.drawTriangle(cx - 2 * r, cy - r, cx + 2 * r, cy - r, cx, cy + 2 * r);
}

static void animBeat(const char *text)
{
    uint32_t end = millis() + 2800;
    for (int f = 0; (int32_t)(end - millis()) > 0; f++) {
        int ph = f % 16, r = 7 + (ph < 8 ? ph : 16 - ph);
        display.clearBuffer();
        drawHeart(64, 24, r / 2 + 4);
        textCentered(text, 60, u8g2_font_7x13B_tr);
        display.sendBuffer(); delay(70);
    }
}
static void animFloat(const char *text)
{
    uint32_t end = millis() + 2800;
    for (int f = 0; (int32_t)(end - millis()) > 0; f++) {
        display.clearBuffer();
        for (int i = 0; i < 7; i++) {
            int x = 10 + i * 17, y = 70 - ((f * 3 + i * 19) % 84);
            if (y > -6 && y < 70) drawHeart(x, y, 2 + (i % 2));
        }
        display.drawBox(0, 26, 128, 14); display.setDrawColor(0);
        textCentered(text, 37, u8g2_font_7x13B_tr); display.setDrawColor(1);
        display.sendBuffer(); delay(60);
    }
}
static void animBanner(const char *text)
{
    uint32_t end = millis() + 2800;
    for (int f = 0; (int32_t)(end - millis()) > 0; f++) {
        display.clearBuffer(); display.drawFrame(0, 0, 128, 64);
        if ((f / 4) % 2) { drawHeart(12, 14, 4); drawHeart(116, 14, 4); }
        else { drawHeartOutline(12, 14, 4); drawHeartOutline(116, 14, 4); }
        textCentered(text, 40, u8g2_font_7x13B_tr);
        display.sendBuffer(); delay(70);
    }
}
static void animStars(const char *text)
{
    static const uint8_t sx[] = { 8, 22, 40, 58, 74, 92, 110, 120, 30, 100 };
    static const uint8_t sy[] = { 8, 18, 6, 20, 10, 4, 16, 26, 30, 30 };
    uint32_t end = millis() + 2800;
    for (int f = 0; (int32_t)(end - millis()) > 0; f++) {
        display.clearBuffer();
        for (int i = 0; i < 10; i++) if ((f + i * 3) % 4) display.drawPixel(sx[i], sy[i]);
        display.drawDisc(104, 14, 9); display.setDrawColor(0); display.drawDisc(100, 11, 8);
        display.setDrawColor(1);
        textCentered(text, 52, u8g2_font_7x13B_tr);
        display.sendBuffer(); delay(90);
    }
}
static void playAnim(uint8_t anim, const char *text)
{
    switch (anim) {
        case AN_FLOAT:  animFloat(text);  break;
        case AN_BANNER: animBanner(text); break;
        case AN_STARS:  animStars(text);  break;
        default:        animBeat(text);   break;
    }
}

/* ===========================================================================
 *  Radio — point-to-point send / receive
 * =========================================================================== */
static volatile bool g_rxFlag = false;
static void onRxDone() { g_rxFlag = true; }

static void radioInit()
{
    SPI.begin();
    int st = radio.begin(868.0, 125.0, 9, 7, 0x2B, 14, 8, 0.0, false);
    if (st != RADIOLIB_ERR_NONE) { g_radioReady = false; Rtt.print(F("radio begin fail ")); Rtt.println(st); return; }
    radio.setDio2AsRfSwitch(true);
    radio.setPreambleLength(PREAMBLE_SYM);   /* long preamble for duty-cycle RX */
    radio.setPacketReceivedAction(onRxDone);
    radio.startReceive();
    g_radioReady = true;
    Rtt.println(F("radio RX ready"));
}

static void sendPreset(int idx)
{
    uint8_t buf[48]; buf[0] = MSG_MAGIC; buf[1] = kPresets[idx].anim;
    int n = 0; const char *t = kPresets[idx].text;
    while (t[n] && n < 40) { buf[2 + n] = (uint8_t)t[n]; n++; }
    display.clearBuffer(); textCentered("Sending...", 30, u8g2_font_7x13B_tr);
    drawHeartOutline(64, 48, 4); display.sendBuffer();

    int st = g_radioReady ? radio.transmit(buf, 2 + n) : RADIOLIB_ERR_UNKNOWN;
    if (g_radioReady) radio.startReceive();

    display.clearBuffer();
    if (st == RADIOLIB_ERR_NONE) { textCentered("Sent", 30, u8g2_font_7x13B_tr); drawHeart(64, 48, 5); chimeSent(); }
    else { textCentered("Send failed", 30, u8g2_font_7x13B_tr); Rtt.print(F("tx fail ")); Rtt.println(st); }
    display.sendBuffer(); delay(500);
    playAnim(kPresets[idx].anim, kPresets[idx].text);   /* preview what you sent */
}

static void wakeScreen();
static void handleIncoming()
{
    uint8_t buf[64]; int len = radio.getPacketLength();
    int st = radio.readData(buf, len); g_lastRssi = radio.getRSSI();
    radio.startReceive();
    if (st != RADIOLIB_ERR_NONE || len < 2 || buf[0] != MSG_MAGIC) return;
    char text[48]; int n = len - 2; if (n > 46) n = 46;
    memcpy(text, buf + 2, n); text[n] = 0;
    Rtt.print(F("RX: ")); Rtt.println(text);
    chimeIncoming();
    playAnim(buf[1], text);
}

/* ===========================================================================
 *  Battery + UI screens
 * =========================================================================== */
static void readBattery()
{
    analogReference(AR_INTERNAL); analogReadResolution(12); analogOversampling(8);
    uint32_t acc = 0; for (int i = 0; i < 8; i++) { acc += analogRead(PIN_VBAT_MON); delay(1); }
    g_battMv = (int)((acc / 8.0f) / 4095.0f * 3600.0f * VBAT_DIVIDER);
}
static int battPct() { int p = (g_battMv - 3300) * 100 / 900; return p < 0 ? 0 : p > 100 ? 100 : p; }

enum Screen { SCR_HOME, SCR_SETTINGS };
static Screen g_screen = SCR_HOME;
static int    g_sel = 0;
static bool   g_dirty = true;

static void drawBattIcon(int x, int y)
{
    int p = battPct();
    display.drawFrame(x, y, 14, 7); display.drawBox(x + 14, y + 2, 2, 3);
    display.drawBox(x + 1, y + 1, p * 12 / 100, 5);
}

static void drawHome()
{
    display.clearBuffer();
    display.setFont(u8g2_font_6x10_tr);
    display.drawStr(2, 9, "Send a note");
    drawBattIcon(110, 2);
    display.drawHLine(0, 12, 128);
    const int rows = 4, rowH = 12, top = 24;
    int first = g_sel - rows + 1; if (first < 0) first = 0;
    if (first > kNumPresets - rows) first = (kNumPresets > rows) ? kNumPresets - rows : 0;
    display.setFont(u8g2_font_7x13_tr);
    for (int i = 0; i < rows && first + i < kNumPresets; i++) {
        int idx = first + i, y = top + i * rowH;
        if (idx == g_sel) {
            display.drawBox(0, y - 10, 128, rowH); display.setDrawColor(0);
            display.drawStr(4, y, kPresets[idx].text); display.setDrawColor(1);
        } else display.drawStr(4, y, kPresets[idx].text);
    }
    display.sendBuffer();
}

/* ---- Settings screen (edit-in-place) ------------------------------------- */
enum { S_BL, S_CONTRAST, S_SLEEP, S_HAPTIC, S_BEEP, S_BACK, S_COUNT };
static int  g_setSel = 0;
static bool g_setEdit = false;

static void settingValue(int item, char *out, int n)
{
    switch (item) {
        case S_BL:       snprintf(out, n, "%d%%", g_backlight * 100 / 255); break;
        case S_CONTRAST: snprintf(out, n, "%d", g_contrast); break;
        case S_SLEEP:    snprintf(out, n, "%s", kSleepLbl[g_sleepIdx]); break;
        case S_HAPTIC:   snprintf(out, n, "%s", kHapLbl[g_hapticLvl]); break;
        case S_BEEP:     snprintf(out, n, "%s", kBeepLbl[g_beepLvl]); break;
        default:         out[0] = 0; break;
    }
}
static void drawSettings()
{
    static const char *label[] = { "Backlight", "Contrast", "Sleep after",
                                   "Haptic", "Beep", "< Back" };
    display.clearBuffer();
    display.setFont(u8g2_font_6x12_tr); display.drawStr(2, 10, "Settings");
    display.drawHLine(0, 12, 128);
    const int rows = 4, rowH = 12, top = 24;
    int first = g_setSel - rows + 1; if (first < 0) first = 0;
    if (first > S_COUNT - rows) first = S_COUNT - rows;
    display.setFont(u8g2_font_6x10_tr);
    for (int i = 0; i < rows && first + i < S_COUNT; i++) {
        int idx = first + i, y = top + i * rowH;
        bool selRow = (idx == g_setSel);
        if (selRow && !g_setEdit) { display.drawBox(0, y - 9, 128, rowH); display.setDrawColor(0); }
        display.drawStr(3, y, label[idx]);
        char v[12]; settingValue(idx, v, sizeof(v));
        if (v[0]) {
            char shown[16];
            if (selRow && g_setEdit) snprintf(shown, sizeof(shown), ">%s<", v);
            else                     snprintf(shown, sizeof(shown), "%s", v);
            display.drawStr(128 - display.getStrWidth(shown) - 3, y, shown);
        }
        if (selRow && !g_setEdit) display.setDrawColor(1);
    }
    display.sendBuffer();
}
static void adjustSetting(int item, int dir)   /* dir = +1 / -1 */
{
    switch (item) {
        case S_BL: {
            int v = g_backlight + dir * 15; if (v < 15) v = 15; if (v > 255) v = 255;
            g_backlight = v; backlight(g_backlight); } break;
        case S_CONTRAST: {
            int v = g_contrast + dir * 2; if (v < 0) v = 0; if (v > 63) v = 63;
            g_contrast = v; display.setContrast(g_contrast); } break;
        case S_SLEEP:
            g_sleepIdx = (g_sleepIdx + (dir > 0 ? 1 : (int)(sizeof(kSleepSecs) / 2) - 1)) % (sizeof(kSleepSecs) / 2);
            break;
        case S_HAPTIC:
            g_hapticLvl = (g_hapticLvl + (dir > 0 ? 1 : 3)) % 4; buzz(); break;
        case S_BEEP:
            g_beepLvl = (g_beepLvl + (dir > 0 ? 1 : 2)) % 3; beep(2093, 80); break;
    }
}

/* ===========================================================================
 *  Screen sleep (radio stays in RX so messages still arrive & wake it)
 * =========================================================================== */
static void wakeScreen()
{
    if (!g_asleep) return;
    g_asleep = false;
    digitalWrite(PIN_LRA_EN, HIGH); delay(1); drvConfig();   /* DRV back up */
    display.setPowerSave(0);
    backlight(g_backlight);
    if (g_radioReady) radio.startReceive();                  /* full RX while awake */
    g_dirty = true; g_lastActive = millis();
}
static void sleepScreen()
{
    g_asleep = true;
    backlight(0);
    display.setPowerSave(1);                                 /* LCD sleep */
    digitalWrite(PIN_LRA_EN, LOW);                           /* DRV2605 off */
    /* low-power listening: radio wakes every ~cycle to sniff for a preamble;
     * a packet still fires DIO1 -> g_rxFlag -> wakeScreen() + animation */
    if (g_radioReady) radio.startReceiveDutyCycleAuto(PREAMBLE_SYM, 8);
}

/* ===========================================================================
 *  Fault reporter
 * =========================================================================== */
extern "C" __attribute__((used)) void hardfault_report(uint32_t *frame)
{
    uint32_t pc = frame[6]; uint32_t cfsr = *(volatile uint32_t *)0xE000ED28;
    Rtt.print(F("\n*** HARDFAULT PC=0x")); Rtt.print(pc, HEX);
    Rtt.print(F(" CFSR=0x")); Rtt.println(cfsr, HEX);
    backlight(255); display.setPowerSave(0); display.clearBuffer();
    display.setFont(u8g2_font_6x12_tr); display.drawStr(0, 11, "*** HARD FAULT ***");
    char b[26]; snprintf(b, sizeof(b), "PC   %08lX", (unsigned long)pc); display.drawStr(0, 30, b);
    snprintf(b, sizeof(b), "CFSR %08lX", (unsigned long)cfsr); display.drawStr(0, 46, b);
    display.sendBuffer(); while (1) { }
}
extern "C" __attribute__((naked)) void HardFault_Handler(void)
{
    __asm volatile("tst lr,#4\n ite eq\n mrseq r0,msp\n mrsne r0,psp\n"
                   "ldr r1,=hardfault_report\n bx r1\n");
}

static void i2cRecover()
{
    pinMode(PIN_SDA, INPUT_PULLUP); pinMode(PIN_SCL, OUTPUT);
    for (int i = 0; i < 9 && digitalRead(PIN_SDA) == LOW; i++) {
        digitalWrite(PIN_SCL, LOW);  delayMicroseconds(6);
        digitalWrite(PIN_SCL, HIGH); delayMicroseconds(6);
    }
    pinMode(PIN_SDA, OUTPUT);
    digitalWrite(PIN_SDA, LOW);  delayMicroseconds(6);
    digitalWrite(PIN_SCL, HIGH); delayMicroseconds(6);
    digitalWrite(PIN_SDA, HIGH); delayMicroseconds(6);
    pinMode(PIN_SCL, INPUT_PULLUP); pinMode(PIN_SDA, INPUT_PULLUP);
}
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
void loop()
{
    uint32_t now = millis();

    /* incoming message wakes the screen and animates */
    if (g_rxFlag) {
        g_rxFlag = false;
        wakeScreen();
        handleIncoming();
        g_lastActive = millis(); g_dirty = true;
    }

    WheelEv w; BtnEv b; pollInputs(w, b);
    if (Rtt.available()) {
        char c = (char)Rtt.read();
        if (c == 'w' || c == 'k') w = WH_UP;
        else if (c == 's' || c == 'j') w = WH_DOWN;
        else if (c == '\r' || c == '\n' || c == ' ') b = BTN_SHORT;
        else if (c == 'b') b = BTN_LONG;
    }
    bool anyInput = (w != WH_NONE) || (b != BTN_NONE);
    if (anyInput) g_lastActive = now;

    /* sleep / wake handling */
    if (g_asleep) {
        if (anyInput) { wakeScreen(); w = WH_NONE; b = BTN_NONE; }  /* consume wake input */
        else { delay(20); return; }
    } else {
        uint16_t to = kSleepSecs[g_sleepIdx];
        if (to && now - g_lastActive > (uint32_t)to * 1000) { sleepScreen(); delay(20); return; }
    }

    /* periodic battery refresh (~10 s) */
    static uint32_t tBatt = 0;
    if (now - tBatt > 10000) { tBatt = now; readBattery(); if (g_screen == SCR_HOME) g_dirty = true; }

    if (g_screen == SCR_HOME) {
        if (w == WH_DOWN) { g_sel = (g_sel + 1) % kNumPresets; g_dirty = true; }
        if (w == WH_UP)   { g_sel = (g_sel - 1 + kNumPresets) % kNumPresets; g_dirty = true; }
        if (b == BTN_SHORT) { sendPreset(g_sel); g_lastActive = millis(); g_dirty = true; }
        if (b == BTN_LONG)  { g_screen = SCR_SETTINGS; g_setSel = 0; g_setEdit = false; g_dirty = true; }
        if (g_dirty) { drawHome(); g_dirty = false; }
    } else { /* SCR_SETTINGS */
        if (g_setEdit) {
            if (w == WH_UP)   { adjustSetting(g_setSel, +1); g_dirty = true; }
            if (w == WH_DOWN) { adjustSetting(g_setSel, -1); g_dirty = true; }
            if (b == BTN_SHORT || b == BTN_LONG) { g_setEdit = false; g_dirty = true; }
        } else {
            if (w == WH_DOWN) { g_setSel = (g_setSel + 1) % S_COUNT; g_dirty = true; }
            if (w == WH_UP)   { g_setSel = (g_setSel - 1 + S_COUNT) % S_COUNT; g_dirty = true; }
            if (b == BTN_SHORT) {
                if (g_setSel == S_BACK) { g_screen = SCR_HOME; g_dirty = true; }
                else { g_setEdit = true; g_dirty = true; }
            }
            if (b == BTN_LONG) { g_screen = SCR_HOME; g_dirty = true; }
        }
        if (g_dirty) { drawSettings(); g_dirty = false; }
    }

    delay(3);
}

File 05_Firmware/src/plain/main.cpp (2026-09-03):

/* ===========================================================================
 *  SPDX-License-Identifier: MIT
 *  Copyright (c) 2026 Mixed Signal Development GmbH
 *
 *  Doomsday Comms System (D.C.S., SKU OS2601) — plain point-to-point messenger
 *
 *  Everyday preset messages, no animations. Now with:
 *    - Chat history (persisted to internal flash, survives power-off)
 *    - Delivery acknowledgements (receiver auto-ACKs; sender shows a
 *      single tick on send, double tick once the ACK is heard)
 *    - Persistent settings (backlight/contrast/sleep/haptic/beep)
 *
 *  Controls (rev-A wheel, post-bodge mapping):
 *     roll  = scroll / adjust      press = send / select      hold = menu
 * =========================================================================== */
#include <Arduino.h>
#include <Wire.h>
#include <SPI.h>
#include <U8g2lib.h>
#include <Adafruit_DRV2605.h>
#include <RadioLib.h>
#include <Adafruit_LittleFS.h>
#include <InternalFileSystem.h>
#include <HardwarePWM.h>
#include "nrf_gpio.h"
#include "rtt.h"

using namespace Adafruit_LittleFS_Namespace;

#define DISP_ARGS U8G2_R0, PIN_DISPLAY_SCK, PIN_DISPLAY_MOSI, \
                  PIN_DISPLAY_CS_N, PIN_DISPLAY_RS, PIN_DISPLAY_RES
U8G2_ST7565_ERC12864_F_4W_SW_SPI display(DISP_ARGS);

Adafruit_DRV2605 drv;
static bool g_drvReady = false;

SX1262 radio = new Module(PIN_LORA_CS_N, PIN_DIO1, PIN_LORA_RST_N, PIN_BUSY);
static bool  g_radioReady = false;
static float g_lastRssi   = 0;

/* ---- settings (persisted) ------------------------------------------------ */
static uint8_t  g_backlight = 100;
static uint8_t  g_contrast  = 10;
static uint8_t  g_hapticLvl = 2;     /* 0 Off,1 Soft,2 Med,3 Strong */
static uint8_t  g_beepLvl   = 1;     /* 0 Off,1 On,2 Loud */
static uint8_t  g_sleepIdx  = 2;

static const uint16_t    kSleepSecs[] = { 0, 15, 30, 60, 120 };
static const char *const kSleepLbl[]  = { "Off", "15s", "30s", "1m", "2m" };
static const char *const kHapLbl[]    = { "Off", "Soft", "Med", "Strong" };
static const char *const kBeepLbl[]   = { "Off", "On", "Loud" };

static uint32_t g_lastActive = 0;
static bool     g_asleep     = false;
static int      g_battMv     = 0;

/* ---- everyday preset messages ------------------------------------------- */
static const char *const kPresets[] = {
    "On my way",
    "Running late",
    "5 minutes",
    "Almost there",
    "Where are you?",
    "At home",
    "Call me",
    "Yes",
    "No",
    "OK",
    "Lunch?",
    "Need anything?",
    "IOU",
    "Dinner?",
    "Coffee?",
    "Miss you",
    "Thanks!",
};
static const int kNumPresets = sizeof(kPresets) / sizeof(kPresets[0]);

/* ---- wire protocol -------------------------------------------------------
 *   data:  [MSG_MAGIC][PKT_DATA][seq][text...]
 *   ack:   [MSG_MAGIC][PKT_ACK ][seq]
 * MSG_MAGIC differs from the love-messenger (0xC5) so the two pairs never
 * cross-trigger. */
#define MSG_MAGIC    0xC6
#define PKT_DATA     0x00
#define PKT_ACK      0x01

/* ---- radio profile: MAX RANGE -------------------------------------------
 * BOTH boards MUST run this identical build or they can't hear each other at
 * all (a board on SF12 cannot demodulate one on SF9). Flash BOTH before they
 * separate — never change SF/BW/CR/preamble on one alone.
 *
 * SF12 / BW125 / CR4-8 / 22 dBm — the practical maximum range for THIS
 * hardware. Vs the old SF9/14 dBm this is ~+8 dB from SF and +8 dB from power
 * (~+16 dB total, roughly 3-4x range in the open). BW stays 125 kHz on
 * purpose: the modules have no TCXO (plain crystal), and below ~125 kHz the
 * crystal's frequency drift exceeds the receiver's tolerance and the link
 * drops intermittently. 22 dBm is the SX1262 max; note EU868 caps ERP at
 * 14 dBm on 868.0 (fine for personal/field use, your call). */
#define LORA_FREQ    868.0
#define LORA_BW      125.0
#define LORA_SF      12
#define LORA_CR      8
#define LORA_SYNC    0x2B
#define LORA_TX_DBM  22
/* Preamble ~= 1 s of airtime at SF12 (symbol ~32.8 ms) so the duty-cycle RX
 * wake window still catches an incoming message. */
#define PREAMBLE_SYM 32
#define ACK_TIMEOUT  8000            /* ms; round-trip airtime is larger at SF12 */

/* ---- input: press=P0.12, roll R=P0.07, roll L=P0.13 --------------------- */
#define PIN_PRESS   PIN_WHEEL_R
#define PIN_ROLL_R  PIN_PUSH
#define PIN_ROLL_L  PIN_WHEEL_L

enum WheelEv { WH_NONE, WH_DOWN, WH_UP };
enum BtnEv   { BTN_NONE, BTN_SHORT, BTN_LONG };

static void pollInputs(WheelEv &w, BtnEv &b)
{
    w = WH_NONE; b = BTN_NONE;
    const uint32_t DEB = 12, LONG_MS = 600;
    uint32_t now = millis();
    static int lastR = HIGH, lastL = HIGH; static uint32_t tR = 0, tL = 0;
    int r = digitalRead(PIN_ROLL_R), l = digitalRead(PIN_ROLL_L);
    if (r != lastR && now - tR > DEB) { tR = now; lastR = r; if (r == LOW) w = WH_DOWN; }
    if (l != lastL && now - tL > DEB) { tL = now; lastL = l; if (l == LOW) w = WH_UP;   }
    static int lastP = HIGH; static uint32_t tP = 0, downAt = 0; static bool longFired = false;
    int p = digitalRead(PIN_PRESS);
    if (p != lastP && now - tP > DEB) {
        tP = now; lastP = p;
        if (p == LOW) { downAt = now; longFired = false; }
        else if (!longFired) b = BTN_SHORT;
    }
    if (p == LOW && !longFired && now - downAt >= LONG_MS) { longFired = true; b = BTN_LONG; }
}
static bool pressDown() { return digitalRead(PIN_PRESS) == LOW; }

/* ---- haptics ------------------------------------------------------------- */
static void drvConfig() { if (g_drvReady) { drv.useLRA(); drv.selectLibrary(6); drv.setMode(DRV2605_MODE_INTTRIG); } }
static void haptic(uint8_t fx)
{
    if (!g_drvReady || g_hapticLvl == 0) return;
    drv.setWaveform(0, fx); drv.setWaveform(1, 0); drv.go();
}
static void buzz() { static const uint8_t fx[] = { 0, 1, 16, 47 }; haptic(fx[g_hapticLvl]); }
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

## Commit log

2026-09-03 Updated 3D model
    [K2601 DCS.step]
2026-09-06 Updated Gerbers and PCB
    [dcs.kicad_pcb]
